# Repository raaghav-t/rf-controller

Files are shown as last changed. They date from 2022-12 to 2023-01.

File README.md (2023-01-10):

# BEAMO

BEAMO is a simple, low-cost RF remote controller for robots and toys based on the common nRF24L01+ and its more ubiquitous counterfeits. 32 may be operated in the same space by selecting different channels using the configuration DIP switch.

The board itself is a simple 2-layer PCB designed to be operated without an enclosure. There are mounting holes to allow attachment of a custom grip.

Example receiver code has been tested on an Arduino Uno using a matching nRF24L01+ module.

# Firmware

The remote is intended for real-time control of a vehicle. As such, it sends button updates at a minimum of every 100ms. When the data changes, it may send as frequently as every 10ms.

The remote firmware was built in PlatformIO (for Raspberry Pi Pico) but should also be portable to the Arduino IDE. The receiver example for Arduino Uno is built in the Arduino IDE.

# BOM

| Reference | Name | Approx Cost | Description |
| :-: | :--  | :-: | :-- |
| RZ1 | [RP2040-Zero](https://www.aliexpress.us/item/3256804095235134.html) | $3.25 | Inexpensive RP2040-based microcontroller board |
| J1 | [nRF24L01+ module](https://www.amazon.com/gp/product/B082VLTTTX) | $2.60/pair | RF module (affixed with [2x4 0.1" connector](https://www.amazon.com/dp/B01IHBCO2K)) |
| SW1-4, SW6-8 | [TS02-66-50-BK-100-SCR-D](https://www.digikey.com/en/products/detail/cui-devices/TS02-66-50-BK-100-SCR-D/15634357)| $0.56 per 7 | Pushbuttons (low-force) |
| SW10 | [DS04-254-1L-05BK](https://www.digikey.com/en/products/detail/cui-devices/DS04-254-1L-05BK/11310878) | $0.64 | 5-position DIP switch |
| SW5 | [PS4 controller joystick](https://www.amazon.com/dp/B09WDNSBBR) | $1.30 | Generic PS4 joystick (ALPS TKJXV1224-like) |
| SW9 | [0.1" SPDT switch](https://www.amazon.com/dp/B09R43HCY3) | $0.10 | Slide switch (for power) |
| BT1 | [2xAA battery holder](https://www.amazon.com/dp/B013GNC08C) | $0.75 | Battery holder (held on with double-sided tape) |

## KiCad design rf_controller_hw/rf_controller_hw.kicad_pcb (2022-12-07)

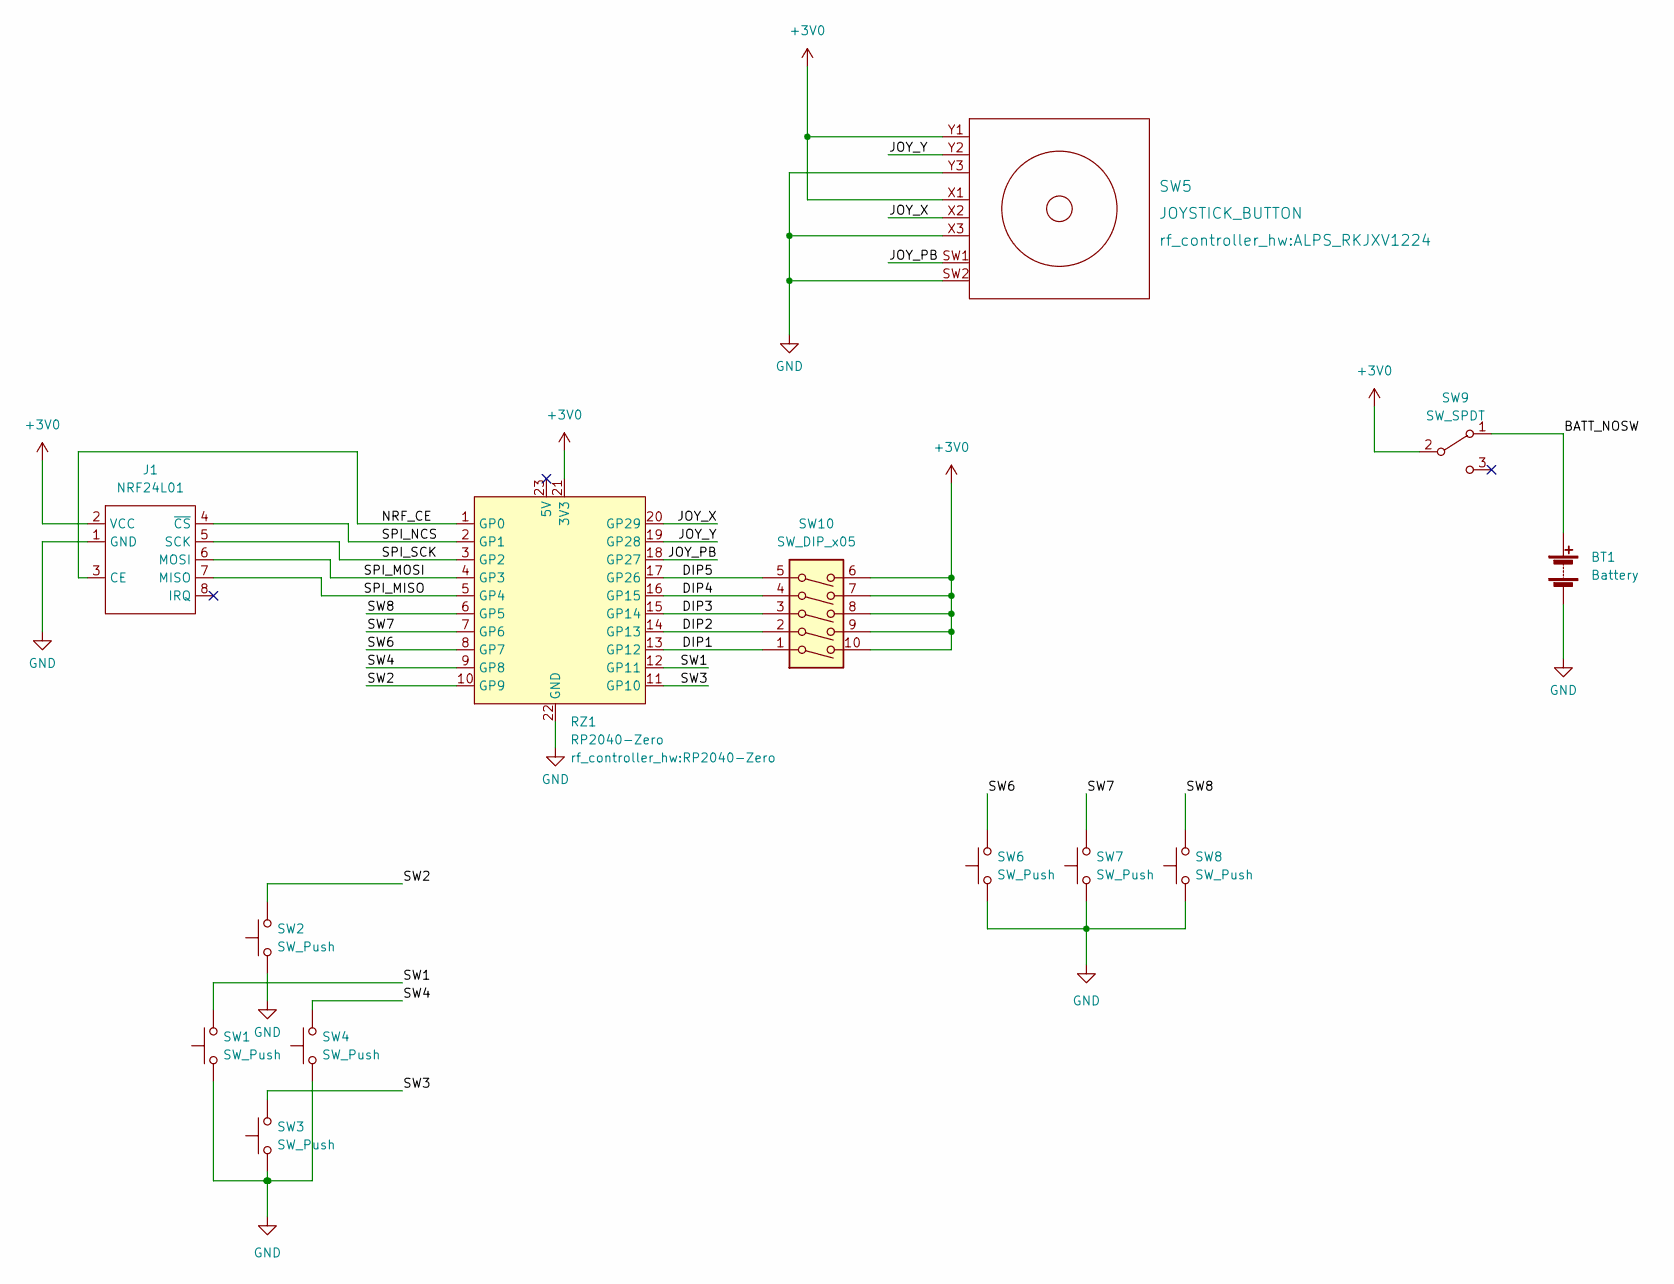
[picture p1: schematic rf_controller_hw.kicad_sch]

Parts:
BT1: Battery; 2AA_BATTERY
J1: NRF24L01; NRF24L01+
RZ1: RP2040-Zero
SW1, SW2, SW3, SW4, SW6, SW7, SW8: SW_Push; SW_PUSH_6mm_H5mm
SW5: JOYSTICK_BUTTON; ALPS_RKJXV1224
SW9: SW_SPDT; PinHeader_1x03_P2.54mm_Vertical
SW10: SW_DIP_x05; SW_DIP_SPSTx05_Slide_9.78x14.88mm_W7.62mm_P2.54mm

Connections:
+3V0: J1.2 (VCC), RZ1.21 (3V3), SW5.X1, SW5.Y1, SW9.2 (B), SW10.6, SW10.7, SW10.8, SW10.9, SW10.10
/BATT_NOSW: BT1.1 (+), SW9.1 (A)
/DIP1: RZ1.13 (GP12), SW10.1
/DIP2: RZ1.14 (GP13), SW10.2
/DIP3: RZ1.15 (GP14), SW10.3
/DIP4: RZ1.16 (GP15), SW10.4
/DIP5: RZ1.17 (GP26), SW10.5
/JOY_PB: RZ1.18 (GP27), SW5.SW1
/JOY_X: RZ1.20 (GP29), SW5.X2
/JOY_Y: RZ1.19 (GP28), SW5.Y2
/NRF_CE: J1.3 (CE), RZ1.1 (GP0)
/SPI_MISO: J1.7 (MISO), RZ1.5 (GP4)
/SPI_MOSI: J1.6 (MOSI), RZ1.4 (GP3)
/SPI_NCS: J1.4 (~CS), RZ1.2 (GP1)
/SPI_SCK: J1.5 (SCK), RZ1.3 (GP2)
/SW1: RZ1.12 (GP11), SW1.2
/SW2: RZ1.10 (GP9), SW2.2
/SW3: RZ1.11 (GP10), SW3.2
/SW4: RZ1.9 (GP8), SW4.2
/SW6: RZ1.8 (GP7), SW6.2
/SW7: RZ1.7 (GP6), SW7.2
/SW8: RZ1.6 (GP5), SW8.2
GND: BT1.2 (-), J1.1 (GND), RZ1.22 (GND), SW1.1, SW2.1, SW3.1, SW4.1, SW5.SW2, SW5.X3, SW5.Y3, SW6.1, SW7.1, SW8.1

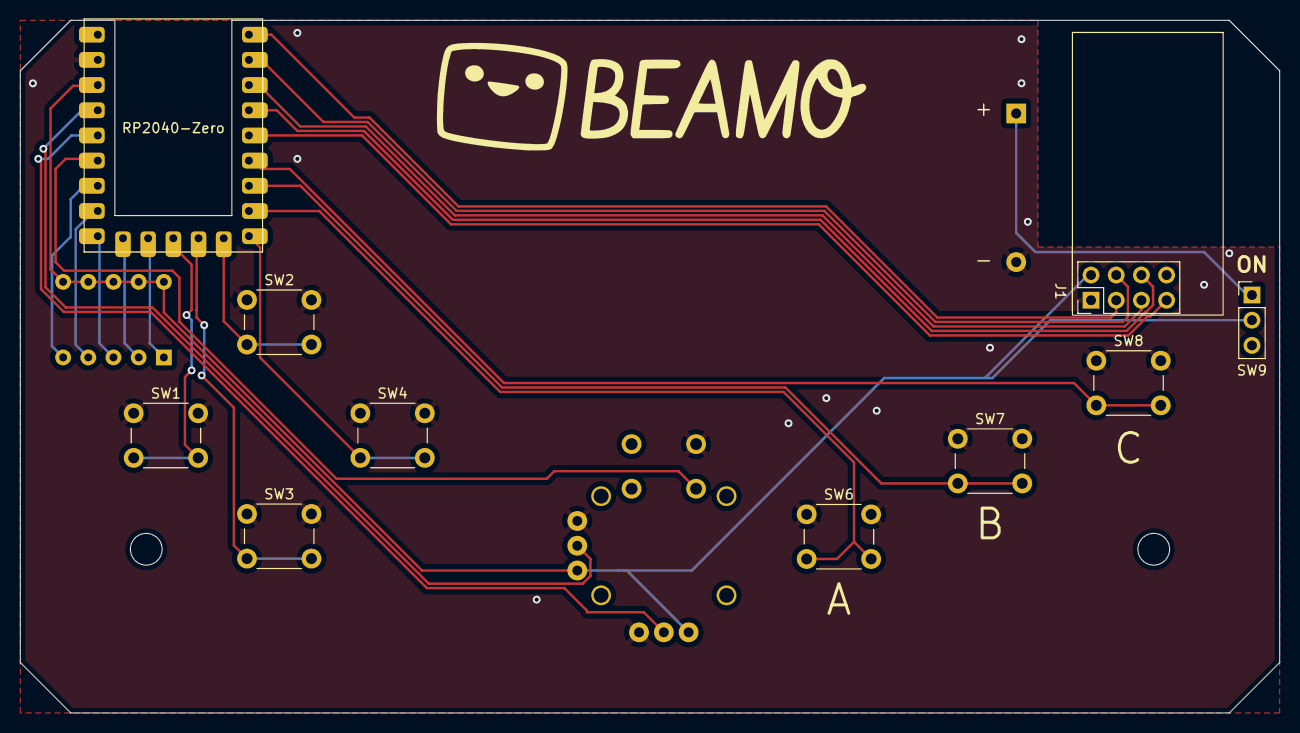
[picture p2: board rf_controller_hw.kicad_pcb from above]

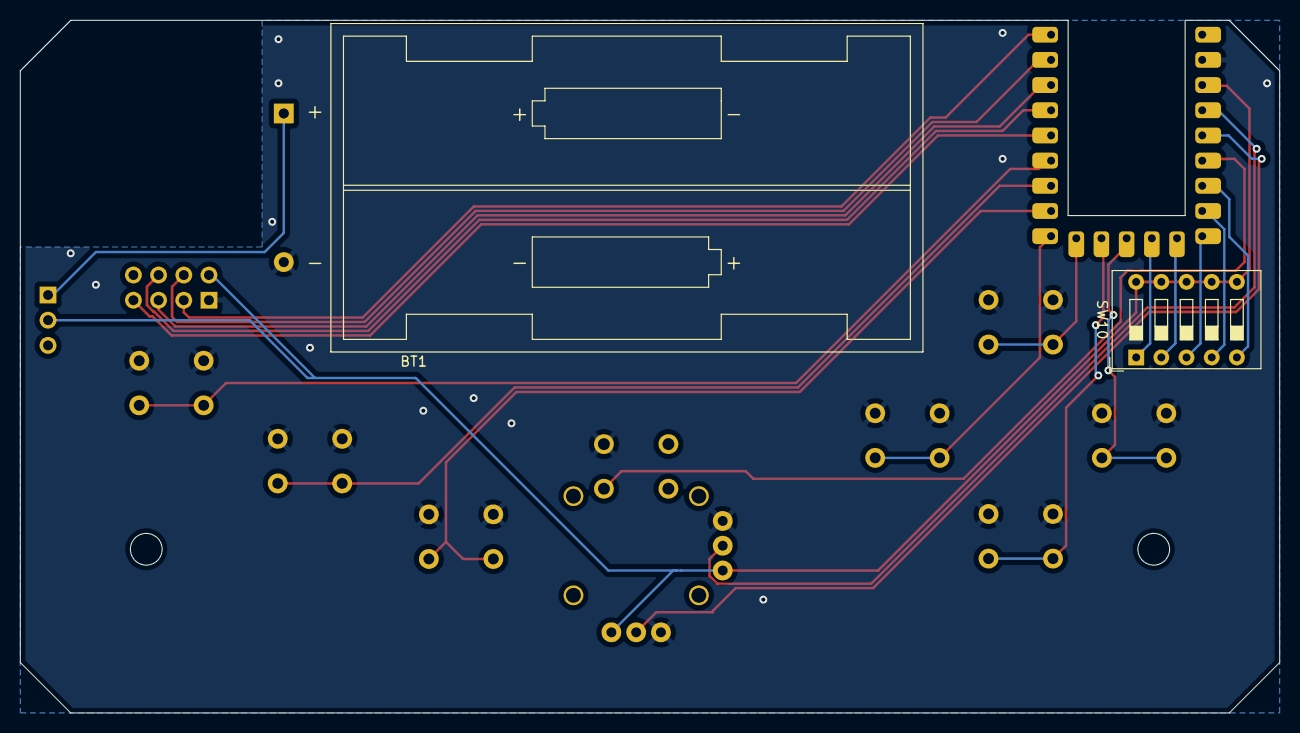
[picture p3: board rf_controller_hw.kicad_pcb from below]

Board: 2 copper layers, 127.0 x 69.8 mm, 13 parts (2 on the bottom side), 23 nets.

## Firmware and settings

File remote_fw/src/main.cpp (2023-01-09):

/* 
 * This file is part of the rf-controller (https://github.com/bnahill/rf-controller).
 * Copyright (c) 2022 Ben Nahill.
 * 
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
 * You should have received a copy of the GNU General Public License 
 * along with this program. If not, see <http://www.gnu.org/licenses/>.
 */

#include <Arduino.h>
#include <SPI.h>
#include <RF24.h>
#include <RF24_config.h>
#include <Adafruit_NeoPixel.h>


static constexpr uint8_t PIN_NRF_CE = 0;
static constexpr uint8_t PIN_NRF_NCS = 1;
static constexpr uint8_t PIN_NRF_SCK = 2;
static constexpr uint8_t PIN_NRF_COPI = 3;
static constexpr uint8_t PIN_NRF_CIPO = 4;

static constexpr uint8_t PIN_SW_UP = 9;
static constexpr uint8_t PIN_SW_DOWN = 10;
static constexpr uint8_t PIN_SW_LEFT = 11;
static constexpr uint8_t PIN_SW_RIGHT = 8;

static constexpr uint8_t PIN_SW_A = 7;
static constexpr uint8_t PIN_SW_B = 6;
static constexpr uint8_t PIN_SW_C = 5;

static constexpr uint8_t PIN_JOYX = 28;
static constexpr uint8_t PIN_JOYY = 29;
static constexpr uint8_t PIN_JOY_PUSH = 27;

static constexpr uint8_t PIN_CONF5 = 26;
static constexpr uint8_t PIN_CONF4 = 15;
static constexpr uint8_t PIN_CONF3 = 14;
static constexpr uint8_t PIN_CONF2 = 13;
static constexpr uint8_t PIN_CONF1 = 12;

static constexpr uint8_t PIN_RGBLED = 16;

// Single RGB LED
Adafruit_NeoPixel strip(1, PIN_RGBLED, NEO_GRB + NEO_KHZ800);

// Compact structure to convey the current input state
typedef struct {
  uint16_t joy_x; //!< Joystick X-axis range 0 (left) - 4095 (right)
  uint16_t joy_y; //!< Joystick Y-axis range 0 (down) - 4095 (up)
  uint8_t up: 1;
  uint8_t down: 1;
  uint8_t left: 1;
  uint8_t right: 1;
  uint8_t a: 1;
  uint8_t b: 1;
  uint8_t c: 1;
  uint8_t joy_push: 1;
} __attribute__((packed)) button_status_t;

static_assert(sizeof(button_status_t) == 5, "button_status_t should be 5B");

// This address can be anything as long as it matches on the receiver side
uint8_t const NRF_ADDRESS[6] = "00001";
RF24 radio(PIN_NRF_CE, PIN_NRF_NCS);

/**
 * @brief Read button input
 * 
 * @return button_status_t 
 */
static button_status_t read_buttons(){
  button_status_t stat = {0};
  
  stat.joy_x = analogRead(PIN_JOYX);
  stat.joy_y = 4096 - analogRead(PIN_JOYY);
  stat.up = 1 - digitalRead(PIN_SW_UP);
  stat.down = 1 - digitalRead(PIN_SW_DOWN);
  stat.left = 1 - digitalRead(PIN_SW_LEFT);
  stat.right = 1 - digitalRead(PIN_SW_RIGHT);
  stat.a = 1 - digitalRead(PIN_SW_A);
  stat.b = 1 - digitalRead(PIN_SW_B);
  stat.c = 1 - digitalRead(PIN_SW_C);
  stat.joy_push = 1 - digitalRead(PIN_JOY_PUSH);
  return stat;
}

static constexpr bool SILENT = true;

/**
 * @brief Compare two inputs of type button_status_t
 * 
 * @param a 
 * @param b 
 * @return true If equal (with analog inputs within some threshold)
 * @return false If not equal
 */
bool status_equal(button_status_t const &a, button_status_t const &b){
  if(a.up != b.up || a.down != b.down || a.left != b.left || a.right != b.right ||
     a.a != b.a || a.b != b.b || a.c != b.c || a.joy_push != b.joy_push){
    return false;
  }
  int32_t const THRESHOLD = 15;
  if(abs((int32_t)a.joy_x - (int32_t)b.joy_x) > THRESHOLD){
    return false;
  }

  if(abs((int32_t)a.joy_y - (int32_t)b.joy_y) > THRESHOLD){
    return false;
  }
  return true;
}

button_status_t last_status = {0};

void setup() {
  if(!SILENT) Serial.begin(9600);

  // Configure the SPI pins to do SPI
  gpio_set_function(PIN_NRF_COPI, GPIO_FUNC_SPI);
  gpio_set_function(PIN_NRF_CIPO, GPIO_FUNC_SPI);
  gpio_set_function(PIN_NRF_SCK, GPIO_FUNC_SPI);

  pinMode(PIN_SW_UP, INPUT_PULLUP);
  pinMode(PIN_SW_DOWN, INPUT_PULLUP);
  pinMode(PIN_SW_LEFT, INPUT_PULLUP);
  pinMode(PIN_SW_RIGHT, INPUT_PULLUP);
  pinMode(PIN_SW_A, INPUT_PULLUP);
  pinMode(PIN_SW_B, INPUT_PULLUP);
  pinMode(PIN_SW_C, INPUT_PULLUP);
  pinMode(PIN_JOYX, INPUT);
  pinMode(PIN_JOYY, INPUT);
  pinMode(PIN_JOY_PUSH, INPUT_PULLUP);

  pinMode(PIN_CONF1, INPUT_PULLDOWN);
  pinMode(PIN_CONF2, INPUT_PULLDOWN);
  pinMode(PIN_CONF3, INPUT_PULLDOWN);
  pinMode(PIN_CONF4, INPUT_PULLDOWN);
  pinMode(PIN_CONF5, INPUT_PULLDOWN);

  analogReadResolution(12);

  delay(1000);

  if (!radio.begin()) {
    if(!SILENT) Serial.println(F("radio hardware is not responding!!"));

    strip.begin();
    strip.setBrightness(50);
    strip.show();
    // Flash red/green if the radio fails to initialize
    for(uint32_t i = 0; i < 40u; i++){
      strip.setPixelColor(0, strip.Color(0, 255, 0));
      strip.show();
      delay(50);
      strip.setPixelColor(0, strip.Color(255, 0, 0));
      strip.show();
      delay(50);
    }
    strip.setPixelColor(0, strip.Color(0, 0, 0));
    strip.show();
    while (1) {}  // hold in infinite loop
  }
  char buffer[64] = {0};
  if(!SILENT){
    snprintf(buffer, sizeof(buffer), "radio hardware initialized %u!!", radio.getChannel());
    Serial.println(buffer);
  }

  uint32_t channel = (digitalRead(PIN_CONF5) << 4) | (digitalRead(PIN_CONF4) << 3) |
                     (digitalRead(PIN_CONF3) << 2) | (digitalRead(PIN_CONF2) << 1) |
                     (digitalRead(PIN_CONF1) << 0);
  
  radio.setChannel(channel);
  if(!SILENT){
    snprintf(buffer, sizeof(buffer), "New channel %u!!", radio.getChannel());
    Serial.println(buffer);
  }
  radio.setPALevel(RF24_PA_LOW);
  radio.openWritingPipe(NRF_ADDRESS);
  radio.stopListening();

  strip.begin();
  strip.setBrightness(50);
  strip.show();

  for(uint32_t i = 0; i < 5u; i++){
    strip.setPixelColor(0, strip.Color(255, 255, 0));
    strip.show();
    delay(50);
    strip.setPixelColor(0, strip.Color(0, 0, 0));
    strip.show();
    delay(50);
  }

  last_status = read_buttons();
}

static constexpr uint32_t SAMPLE_DELAY_MS = 10u;
static constexpr uint32_t MIN_UPDATE_RATE_MS = 100u;
static constexpr uint32_t LED_TIMEOUT_MS = 1000u;
static constexpr uint32_t IDLE_TIMEOUT_MS = 5u * 60u * 1000u;

static uint32_t last_change_ms = 0u;
static uint32_t last_update_ms = 0u;

void loop() {
  // put your main code here, to run repeatedly:
  delay(SAMPLE_DELAY_MS);
  //Serial.println("Line");
  char buffer[128] = {0};
  button_status_t const status = read_buttons();
  if(!status_equal(status, last_status)){
    if(!SILENT){
      snprintf(buffer, sizeof(buffer), "Joy X %u, Y %u, PB %lu!!", status.joy_x, status.joy_y, (uint32_t)status.joy_push);
      Serial.println(buffer);

      snprintf(buffer, sizeof(buffer), "%u %u %u %u %u %u %u",
              status.up, status.down, status.left, status.right,
              status.a, status.b, status.c);
      Serial.println(buffer);
    }
    strip.setPixelColor(0, strip.Color(status.joy_x / 16, status.joy_y / 16, 0));
    strip.show();
    radio.write(&status, sizeof(button_status_t));

    last_change_ms = millis();
    last_update_ms = last_change_ms;
  } else if ( millis() - last_change_ms > MIN_UPDATE_RATE_MS ) {
    radio.write(&status, sizeof(button_status_t));
    last_update_ms = millis();
  }

  if ( millis() - last_change_ms > LED_TIMEOUT_MS ) {
    strip.setPixelColor(0, strip.Color(0, 0, 0));
    strip.show();
  }

  if ( millis() - last_change_ms > IDLE_TIMEOUT_MS ) {
    //sleep_goto_dormant_until_edge_high(10);
  }

  last_status = status;

}

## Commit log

2022-11-19 Initial hardware design commit
    [rf_controller_hw.kicad_pcb, rf_controller_hw.kicad_sch]
2022-11-24 Changed to mechanical keyboard switches
    [rf_controller_hw.kicad_pcb, rf_controller_hw.kicad_sch]
2022-11-28 Finished first draft:
    - Spread out buttons on right
    - Added power switch
    - Added a budget logo
    - Added gerbers for PCB order
    [rf_controller_hw-B_Cu.gbl, rf_controller_hw-B_Mask.gbs, rf_controller_hw-B_Paste.gbp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]
2022-12-07 Fixed a bug in the first board:
    Fixed bug in RP2040-Zero pinout
    Added better logo
    Re-added mounting holes
    Switched to smaller joystick
    [rf_controller_hw-B_Cu.gbl, rf_controller_hw-B_Mask.gbs, rf_controller_hw-B_Paste.gbp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]
2022-12-24 Added first cut of firmware

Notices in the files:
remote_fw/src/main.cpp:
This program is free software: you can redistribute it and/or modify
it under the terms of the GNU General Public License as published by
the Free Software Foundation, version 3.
